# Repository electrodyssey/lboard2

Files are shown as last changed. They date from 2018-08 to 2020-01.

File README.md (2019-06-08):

experimental sound processing board with XC6SLX9-TQG144 and TLV320AIC3204

Work is in progress. 

Currently board is capable of receiving and sending the audio samples with a codec and passes the loopback test from FPGA pins.

FPGA bitstream config is stored inside the STM32F401RE internal flash.

Quick and dirty firmware loader is here: https://github.com/electrodyssey/lboard2flashboot

Working full-duplex aic3204 configuration script is saved in aic3204script directory:

codec receives: MCLK = 11.2896 MHz,

and generates: BLCK = 2.8224 MHz,

WCLK = 44.1 kHz

Please check the CHANGELOG  for the updates

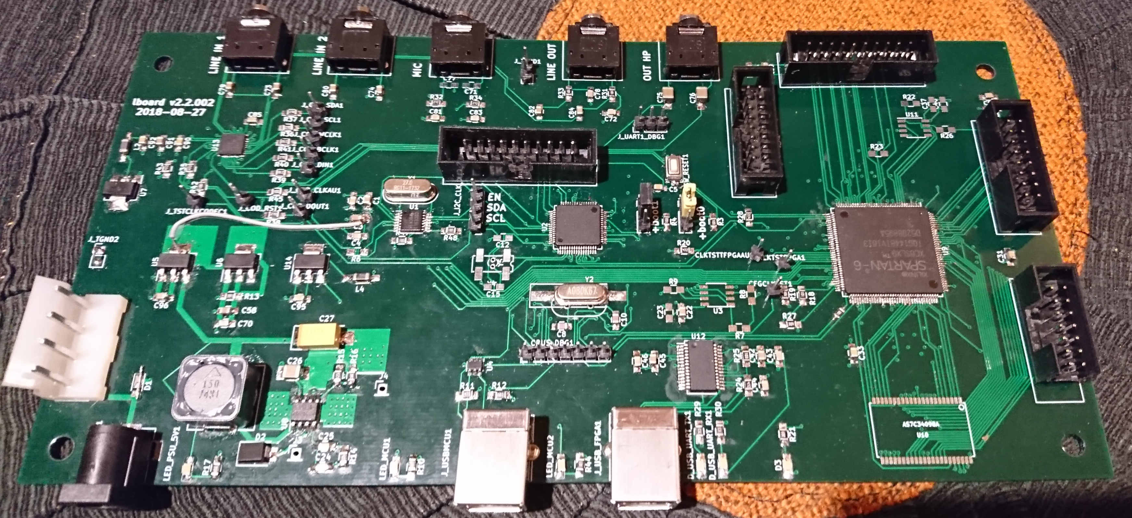
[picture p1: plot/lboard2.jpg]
lboard2


Block diagram:

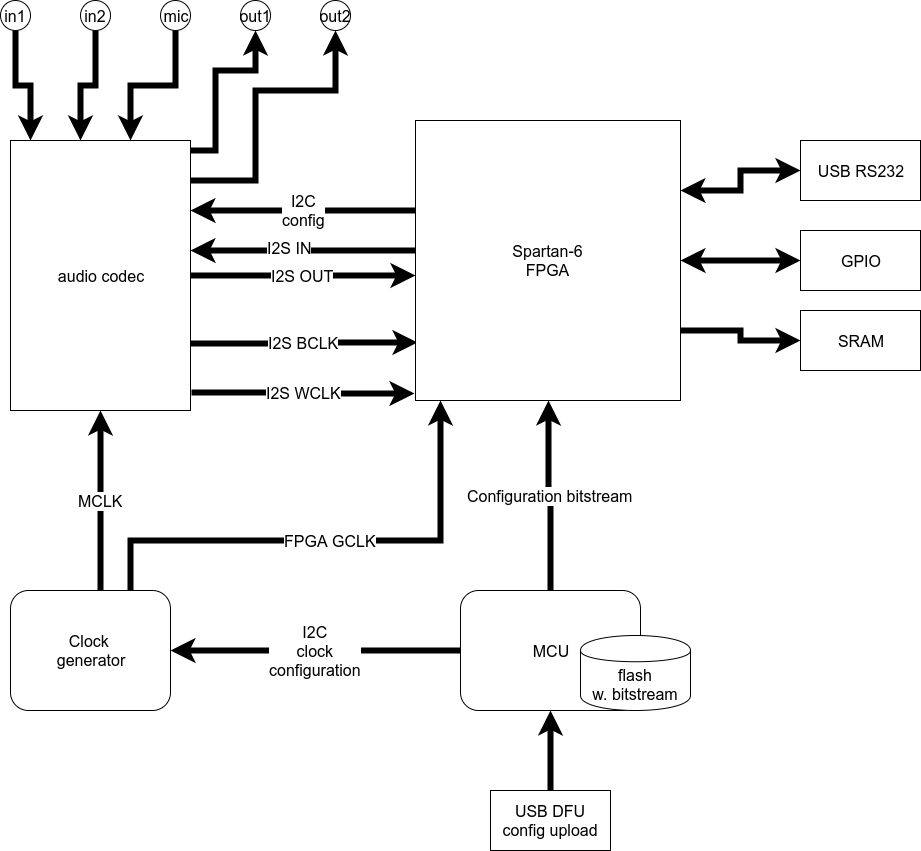
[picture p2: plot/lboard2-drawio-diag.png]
lboard2 block diagram


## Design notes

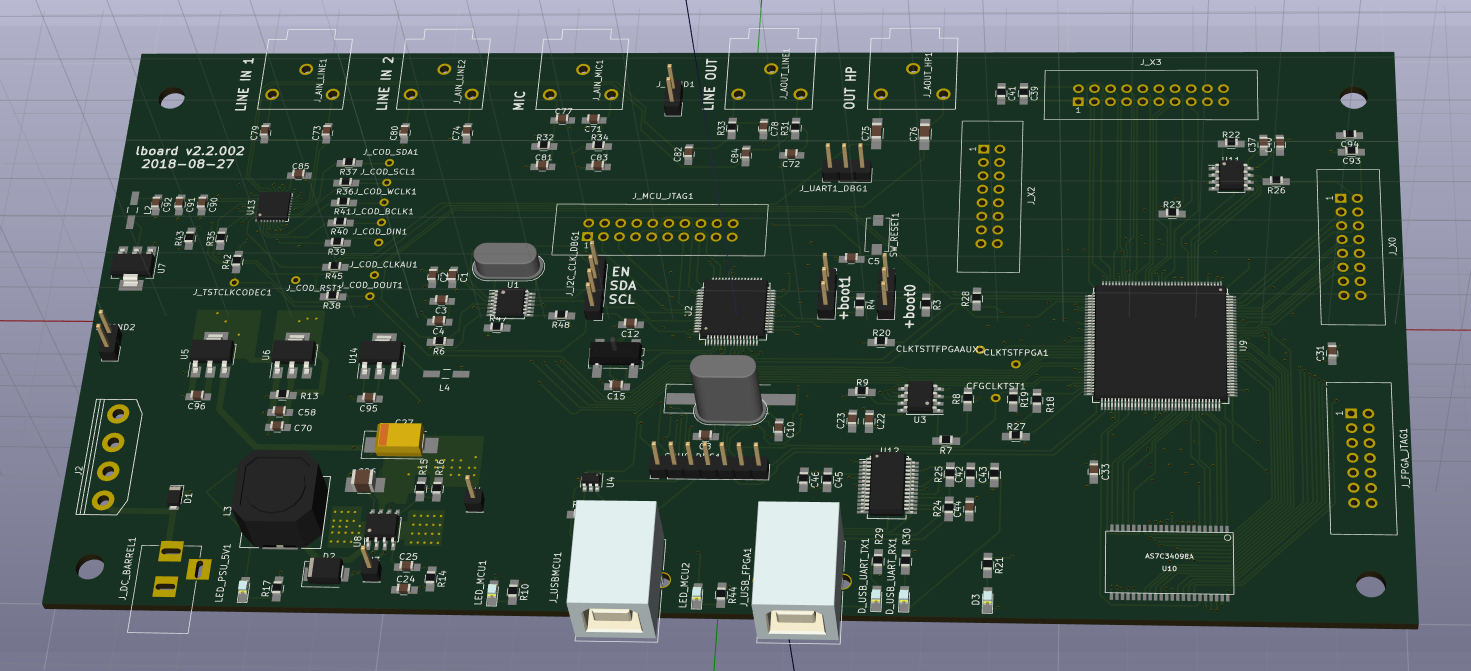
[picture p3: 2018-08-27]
plot/board.png

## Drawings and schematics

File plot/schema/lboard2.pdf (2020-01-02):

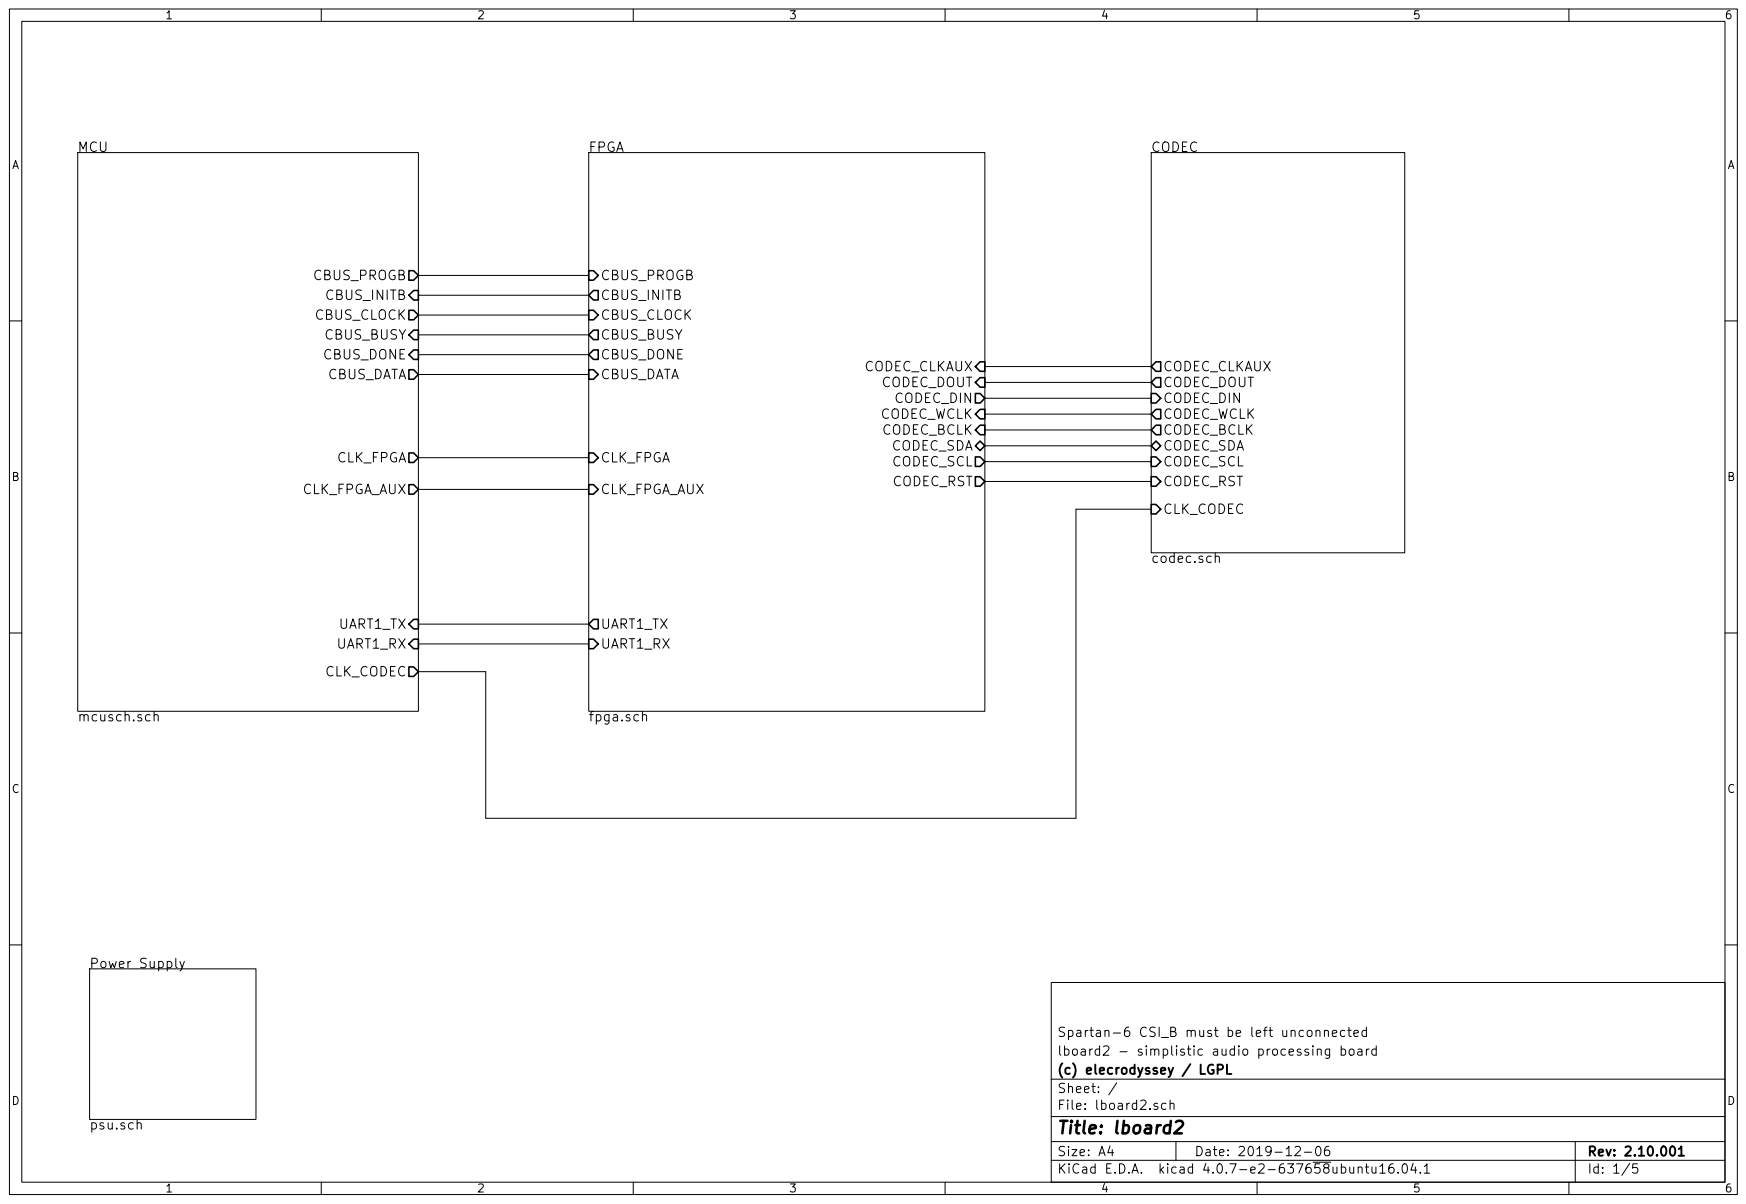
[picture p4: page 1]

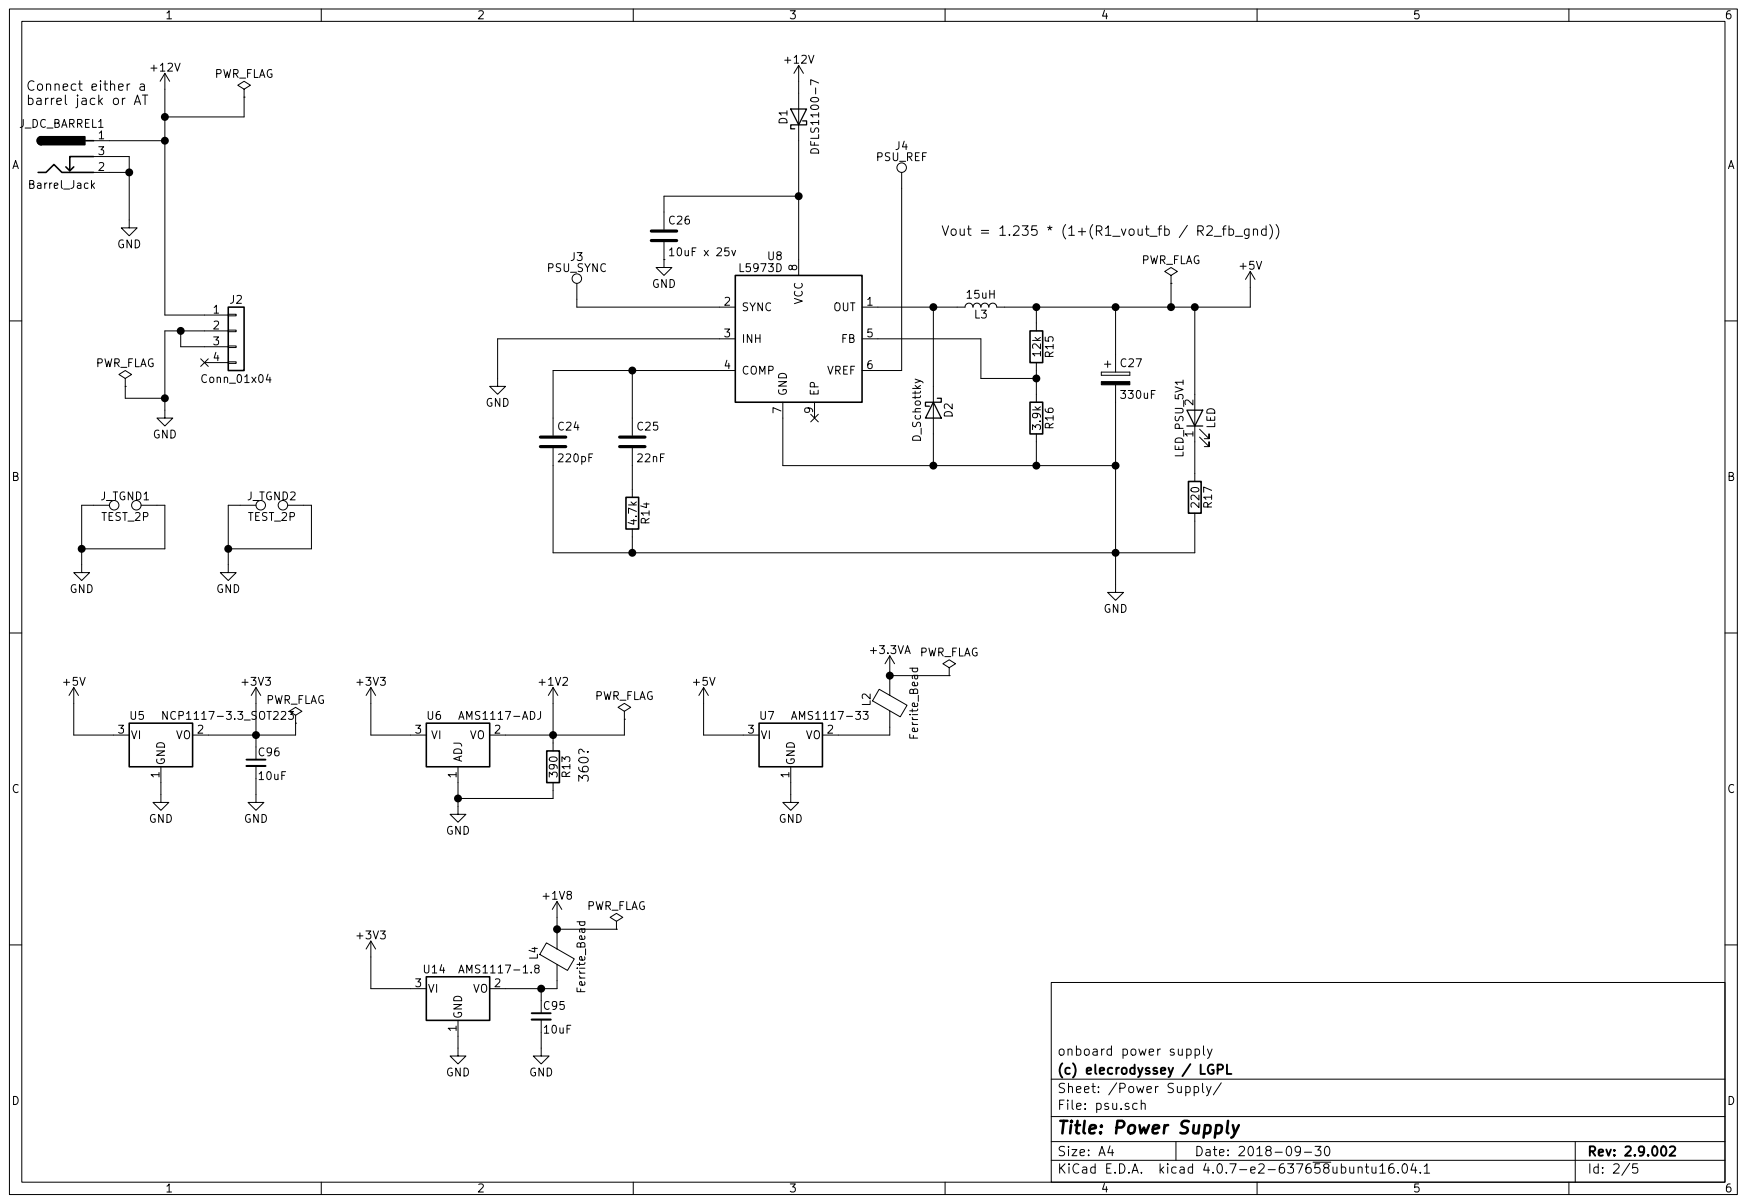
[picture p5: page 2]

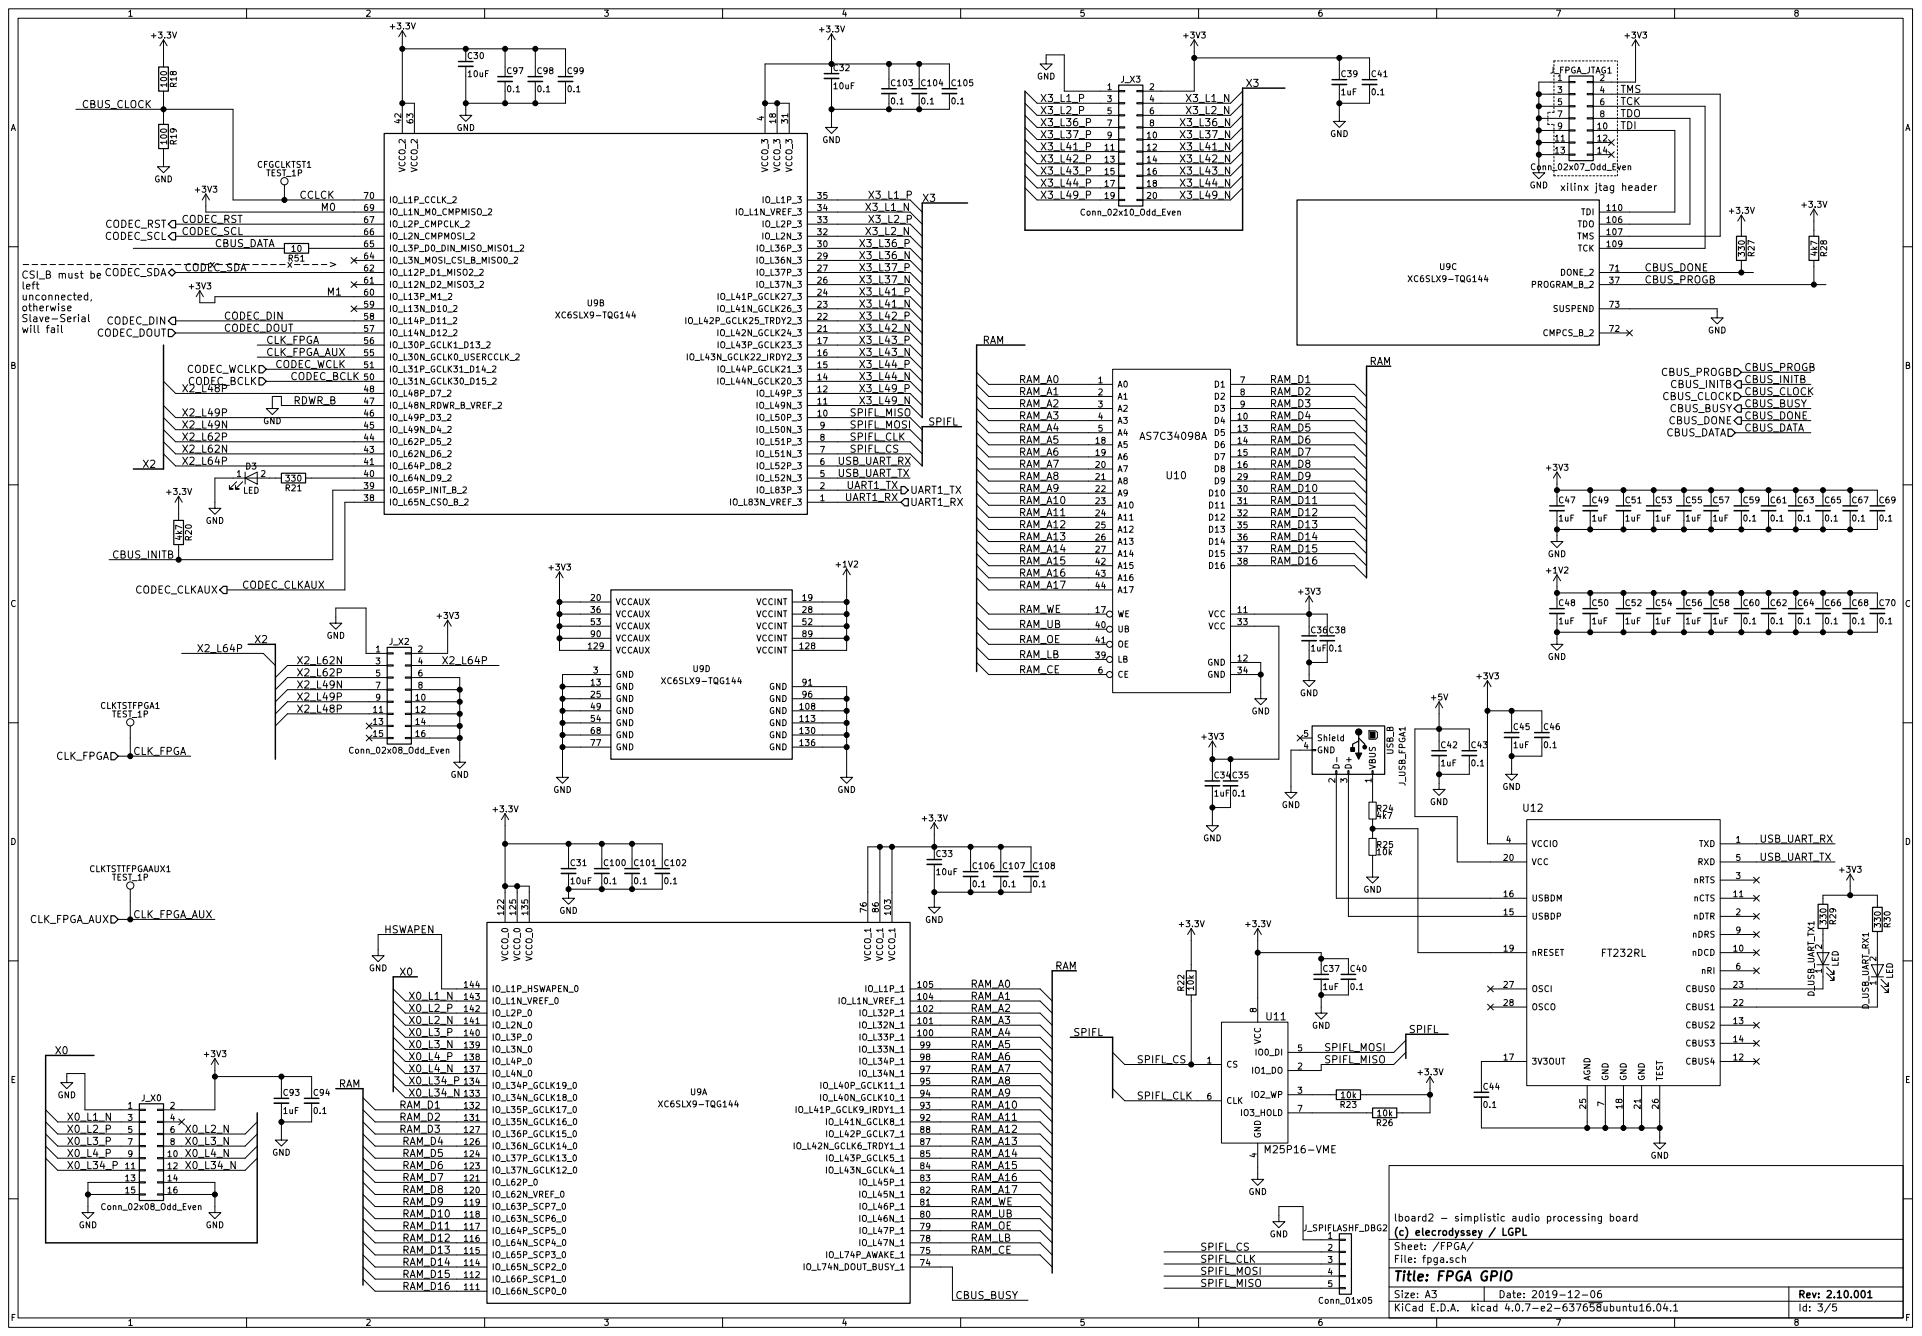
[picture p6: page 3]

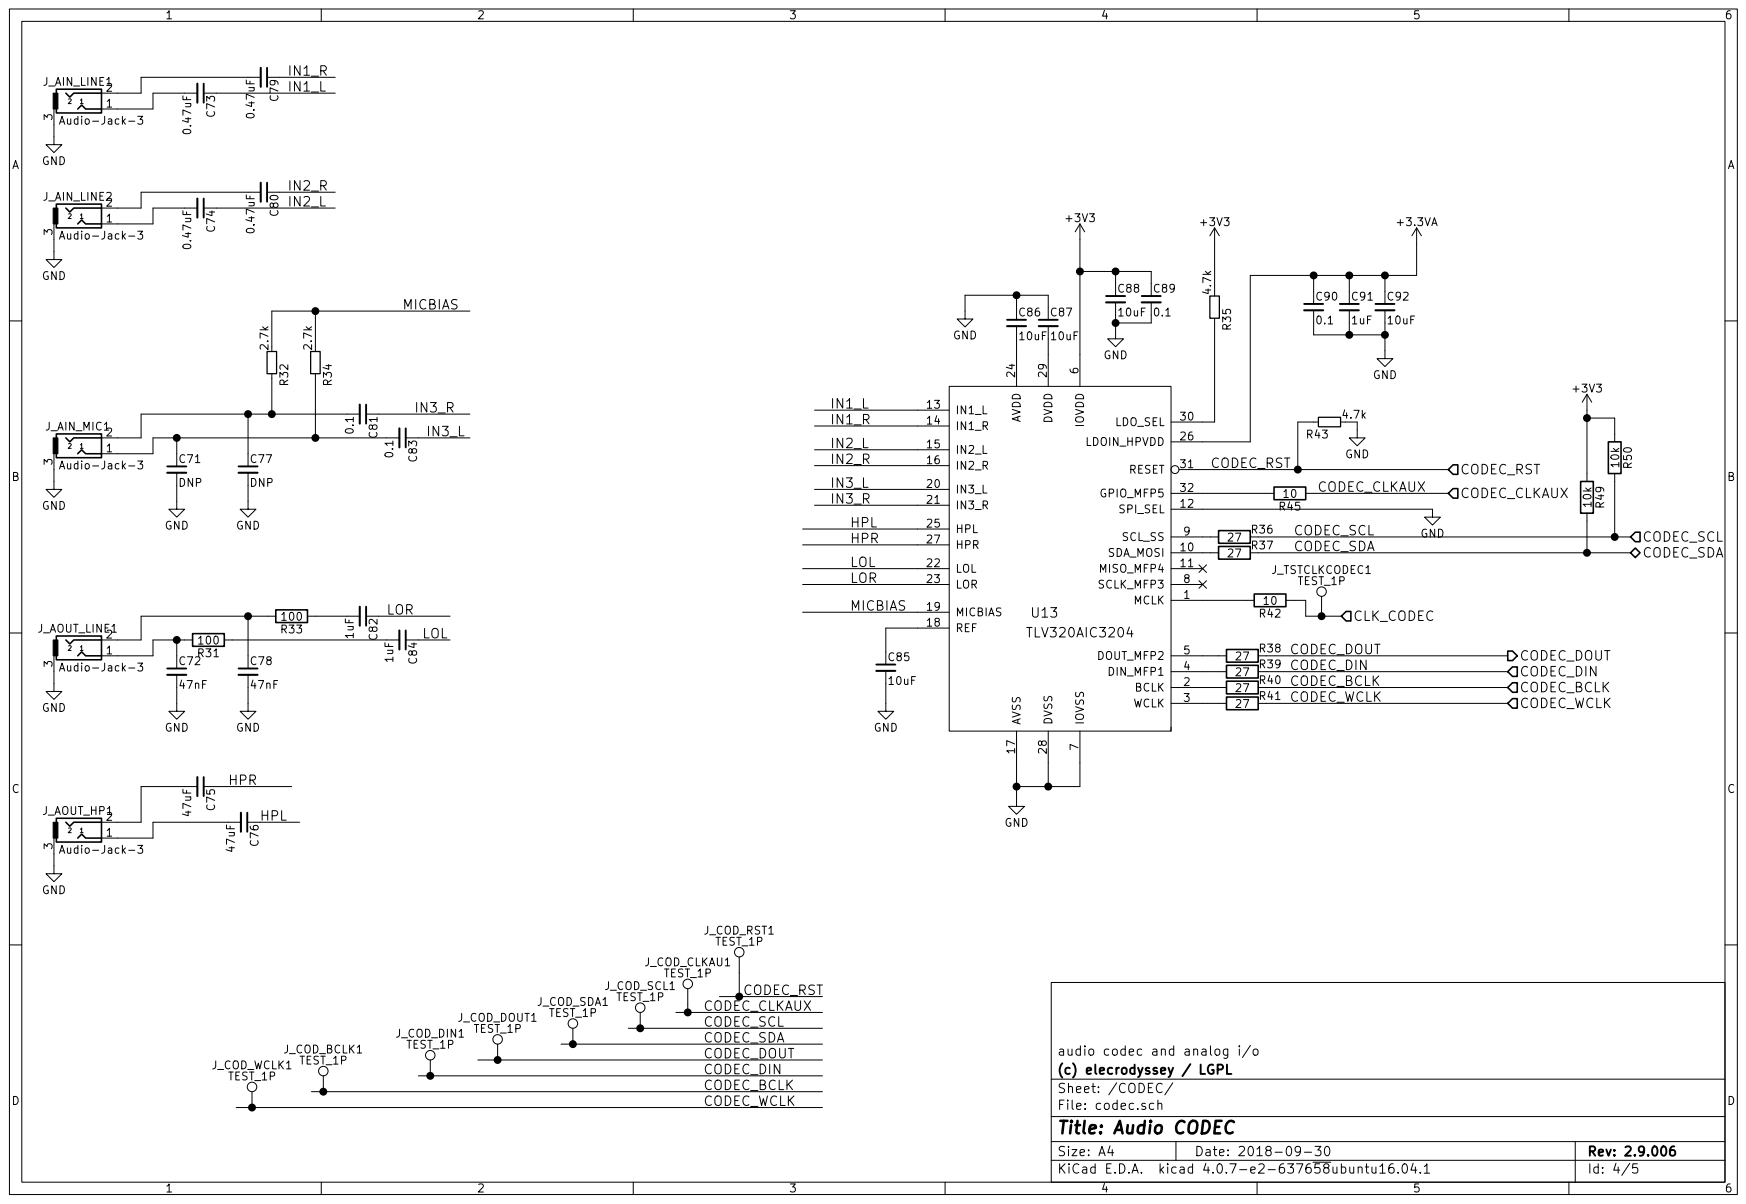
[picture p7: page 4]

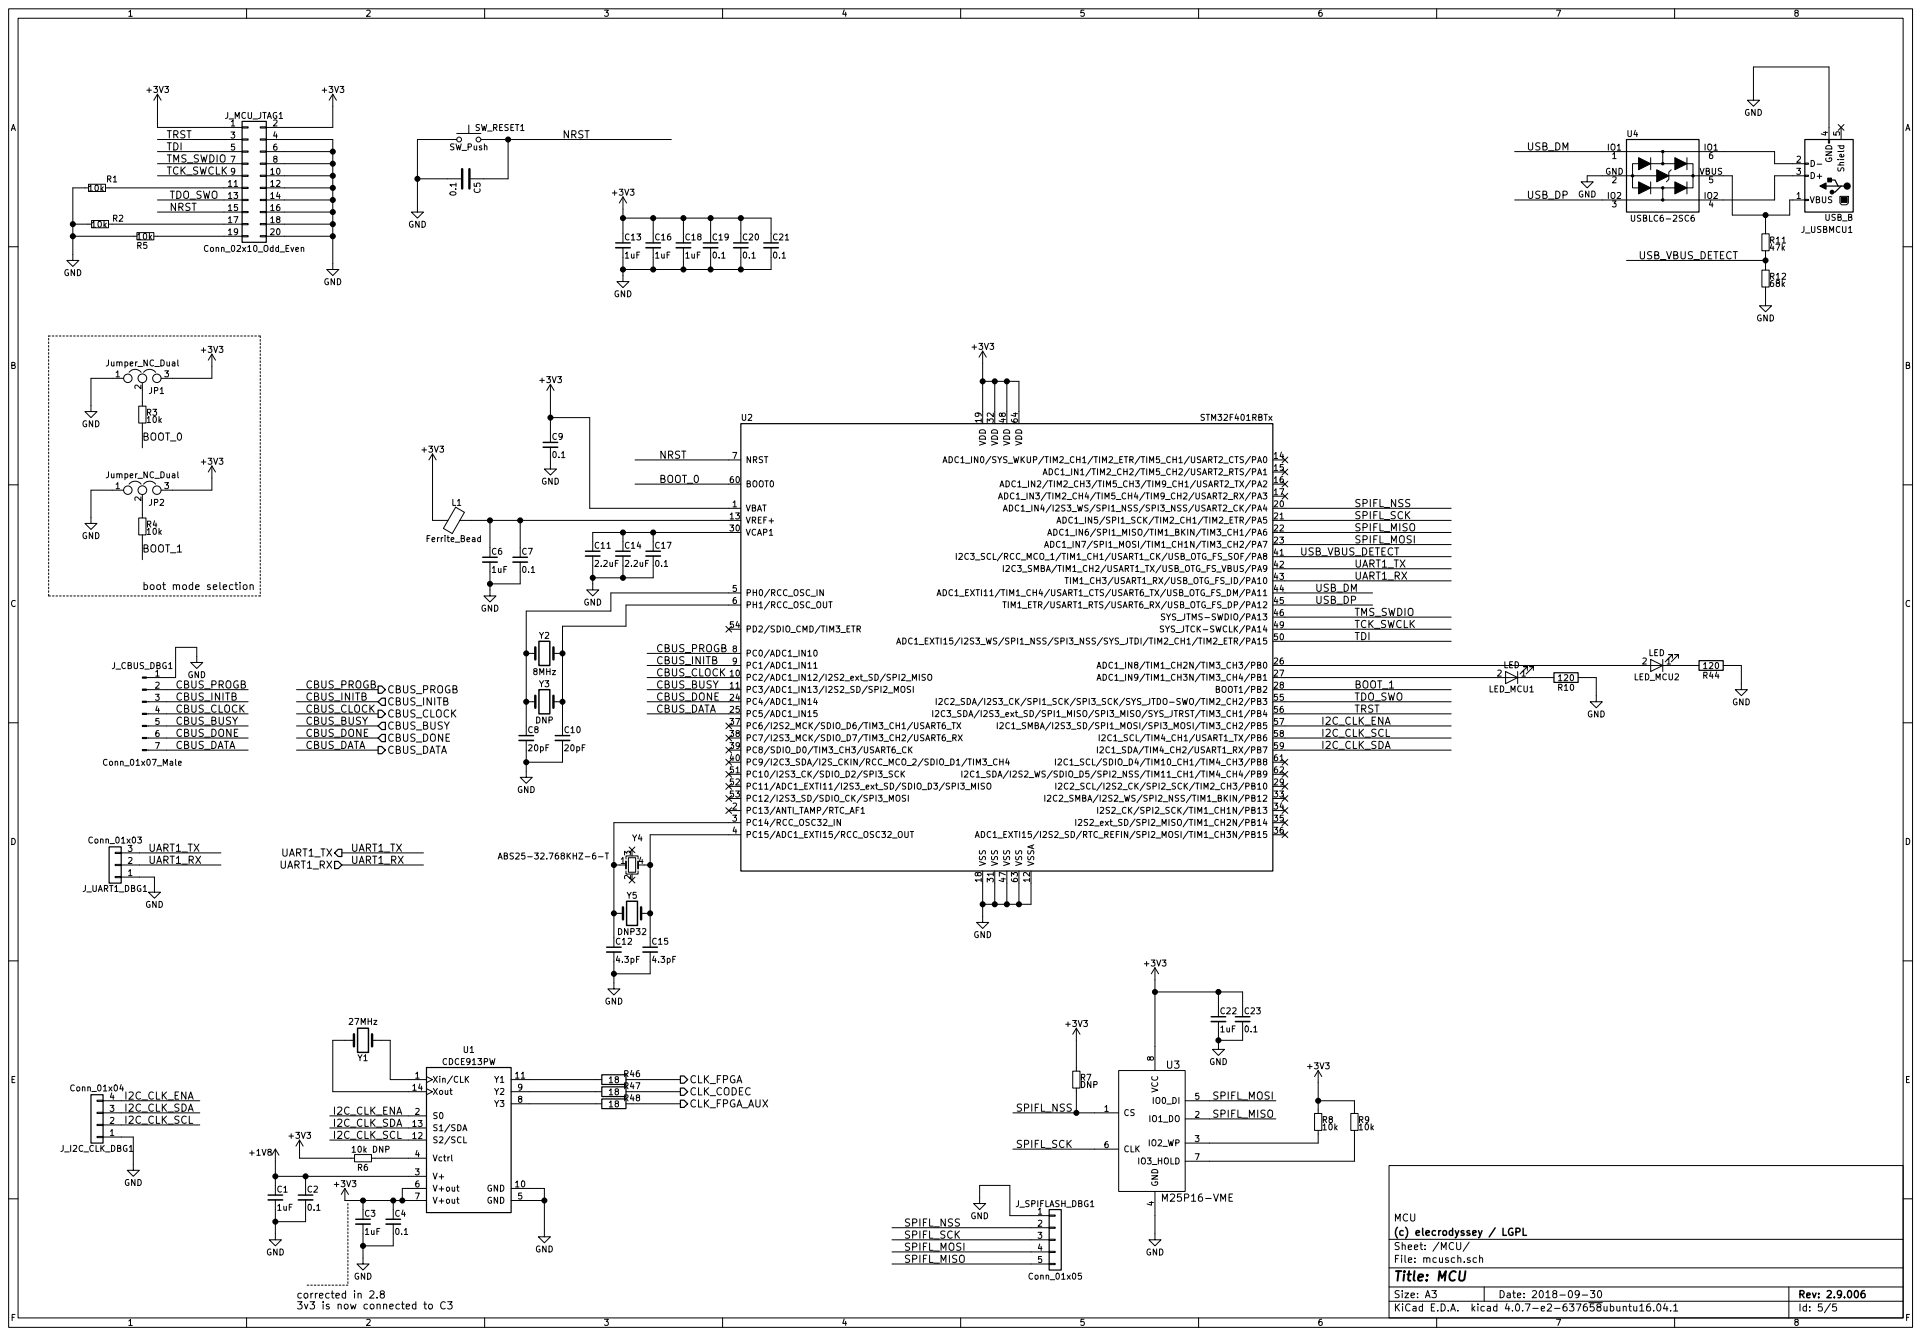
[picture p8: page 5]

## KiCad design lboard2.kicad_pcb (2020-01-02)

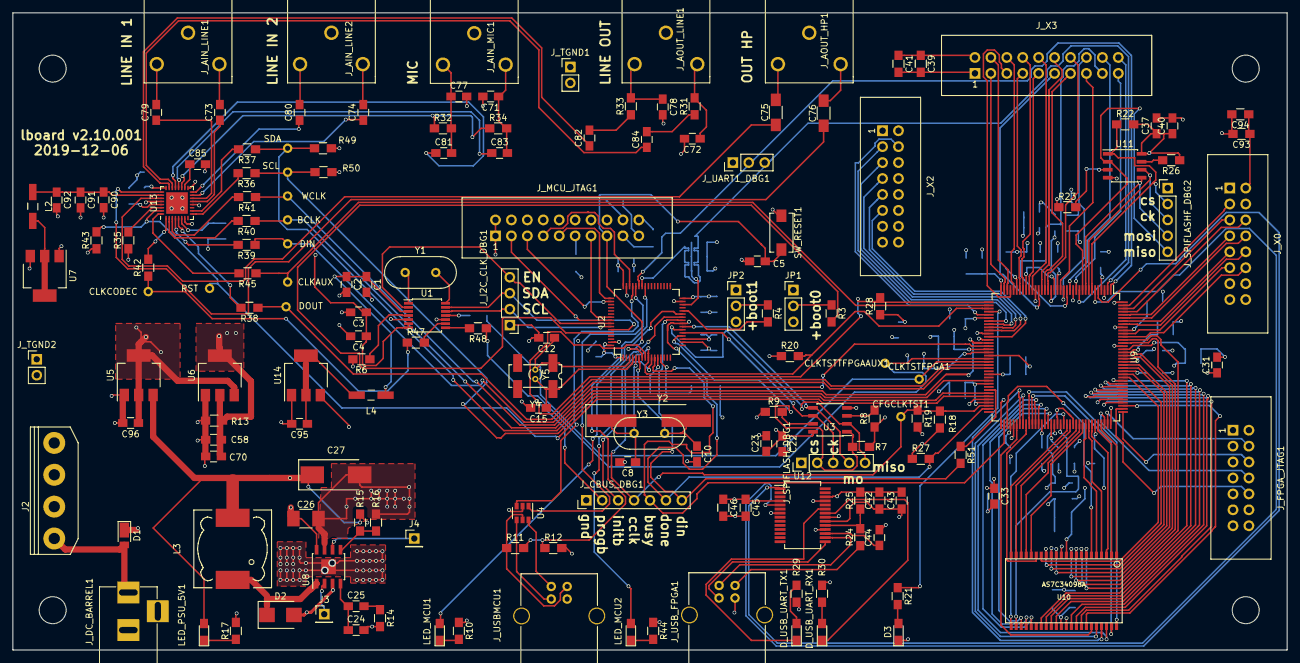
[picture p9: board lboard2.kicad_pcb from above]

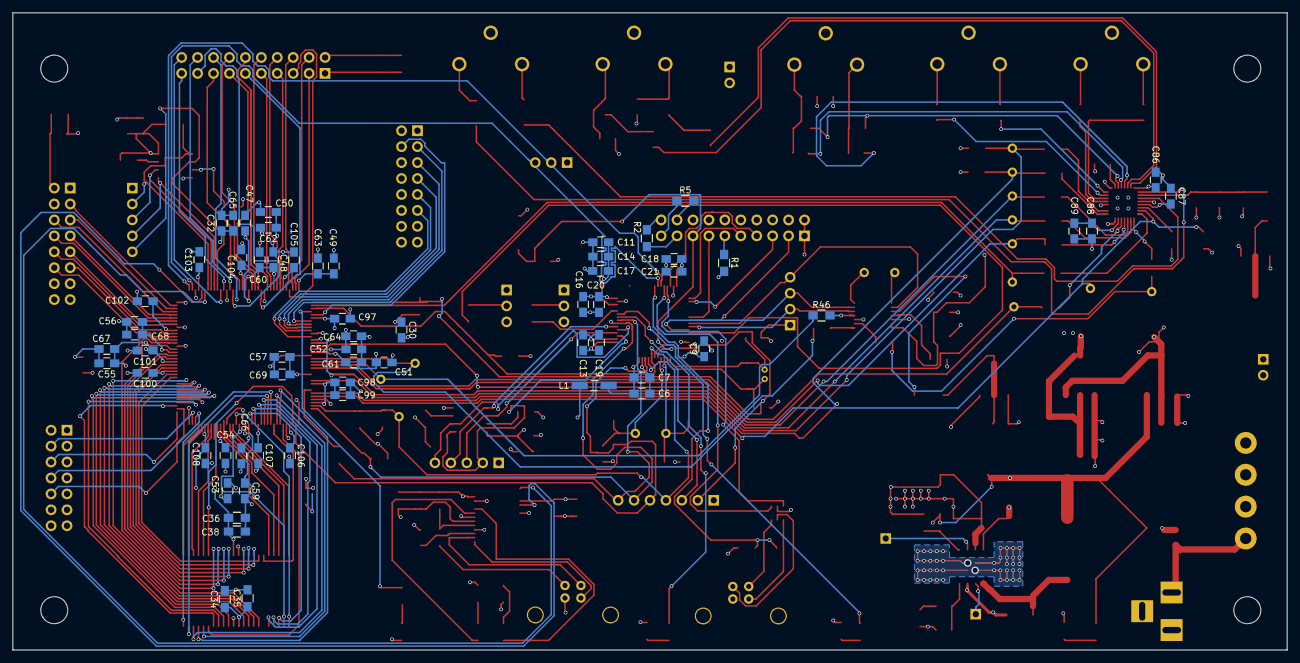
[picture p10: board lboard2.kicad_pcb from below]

Board: 4 copper layers, 203.2 x 101.6 mm, 230 parts (61 on the bottom side), 211 nets.

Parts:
BCLK: TEST_1P; Measurement_Point_Round-TH_Small
C1, C3, C6, C13, C16, C18, C22, C37, C47, C48, C49, C50, C51, C52, C53, C54, C55, C56, C57, C58, C82, C84, C91: 1uF; C_0805_HandSoldering
C2, C4, C5, C7, C9, C17, C19, C20, C21, C23, C40, C44, C59, C60, C61, C62, C63, C64, C65, C66, C67, C68, C69, C70, C81, C83, C89, C90, C97, C98, C99, C100, C101, C102, C103, C104, C105, C106, C107, C108: 0.1; C_0805_HandSoldering
C8, C10: 20pF; C_0805_HandSoldering
C11, C14: 2.2uF; C_0805_HandSoldering
C12, C15: 4.3pF; C_0805_HandSoldering
C24: 220pF; C_0805_HandSoldering
C25: 22nF; C_0805_HandSoldering
C26: 10uF x 25v; C_1210_HandSoldering
C27: 330uF; CP_Tantalum_Case-D_EIA-7343-31_Hand
C30, C31, C32, C33, C85, C86, C87, C88, C92, C95, C96: 10uF; C_0805_HandSoldering
C34, C36, C39, C42, C45, C93: 1uF; R_0805_HandSoldering
C35, C38, C41, C43, C46, C94: 0.1; R_0805_HandSoldering
C71, C77: DNP; C_0805_HandSoldering
C72, C78: 47nF; C_0805_HandSoldering
C73, C74, C79, C80: 0.47uF; C_0805_HandSoldering
C75, C76: 47uF; C_1206_HandSoldering
CFGCLKTST1: TEST_1P; Measurement_Point_Round-TH_Small
CLKAUX: TEST_1P; Measurement_Point_Round-TH_Small
CLKCODEC: TEST_1P; Measurement_Point_Round-TH_Small
CLKTSTFPGA1: TEST_1P; Measurement_Point_Round-TH_Small
CLKTSTTFPGAAUX1: TEST_1P; Measurement_Point_Round-TH_Small
D1: DFLS1100-7; D_PowerDI-123
D2: D_Schottky; D_SMB
D3: LED; LED_0805_HandSoldering
DIN: TEST_1P; Measurement_Point_Round-TH_Small
DOUT: TEST_1P; Measurement_Point_Round-TH_Small
D_USB_UART_RX1: LED; LED_0805_HandSoldering
D_USB_UART_TX1: LED; LED_0805_HandSoldering
J2: Conn_01x04; ATX-PSU-MOLEX-4PIN-5.08mm
J3: PSU_SYNC; Pin_Header_Straight_1x01_Pitch2.54mm
J4: PSU_REF; Pin_Header_Straight_1x01_Pitch2.54mm
JP1, JP2: Jumper_NC_Dual; Pin_Header_Straight_1x03_Pitch2.54mm
J_AIN_LINE1, J_AIN_LINE2: Audio-Jack-3; audiosock-3.5-3pin
J_AIN_MIC1: Audio-Jack-3; audiosock-3.5-3pin
J_AOUT_HP1: Audio-Jack-3; audiosock-3.5-3pin
J_AOUT_LINE1: Audio-Jack-3; audiosock-3.5-3pin
J_CBUS_DBG1: Conn_01x07_Male; Pin_Header_Straight_1x07_Pitch2.54mm
J_DC_BARREL1: Barrel_Jack; BARREL_JACK
J_FPGA_JTAG1: Conn_02x07_Odd_Even; IDC_Header_Straight_14pins
J_I2C_CLK_DBG1: Conn_01x04; Pin_Header_Straight_1x04_Pitch2.54mm
J_MCU_JTAG1: Conn_02x10_Odd_Even; IDC_Header_Straight_20pins
J_SPIFLASHF_DBG2: Conn_01x05; Pin_Header_Straight_1x05_Pitch2.54mm
J_SPIFLASH_DBG1: Conn_01x05; Pin_Header_Straight_1x05_Pitch2.54mm
J_TGND1, J_TGND2: TEST_2P; Pin_Header_Straight_1x02_Pitch2.54mm
J_UART1_DBG1: Conn_01x03; Pin_Header_Straight_1x03_Pitch2.54mm
J_USBMCU1: USB_B
J_USB_FPGA1: USB_B
J_X0, J_X2: Conn_02x08_Odd_Even; IDC_Header_Straight_16pins
J_X3: Conn_02x10_Odd_Even; IDC_Header_Straight_20pins
L1, L2, L4: Ferrite_Bead; Choke_SMD_1206_Handsoldering
L3: 15uH; Choke_SMD_12x12mm_h8mm
LED_MCU1, LED_MCU2: LED; LED_0805_HandSoldering
LED_PSU_5V1: LED; LED_0805_HandSoldering
MH0, MH1, MH2, MH3: MountingHole_4.3mm_M4_DIN965
R1, R2, R3, R4, R5, R8, R9, R22, R23, R25, R26, R49, R50: 10k; R_0805_HandSoldering
R6: 10k DNP; R_0805_HandSoldering
R7: DNP; R_0805_HandSoldering
R10, R44: 120; R_0805_HandSoldering
R11: 47k; R_0805_HandSoldering
R12: 68k; R_0805_HandSoldering
R13: 390; R_0805_HandSoldering
R14, R35, R43: 4.7k; R_0805_HandSoldering
R15: 12k; R_0805_HandSoldering
R16: 3.9k; R_0805_HandSoldering
R17: 220; R_0805_HandSoldering
R18, R19, R31, R33: 100; R_0805_HandSoldering
R20, R24, R28: 4k7; R_0805_HandSoldering
R21, R27, R29, R30: 330; R_0805_HandSoldering
R32, R34: 2.7k; R_0805_HandSoldering
R36, R37, R38, R39, R40, R41: 27; R_0805_HandSoldering
R42, R45, R51: 10; R_0805_HandSoldering
R46, R47, R48: 18; R_0805_HandSoldering
RST: TEST_1P; Measurement_Point_Round-TH_Small
SCL: TEST_1P; Measurement_Point_Round-TH_Small
SDA: TEST_1P; Measurement_Point_Round-TH_Small
SW_RESET1: SW_Push; SW_SPST_EVQPE1
U1: CDCE913PW; TSSOP-14_4.4x5mm_Pitch0.65mm
U2: STM32F401RBTx; LQFP-64_10x10mm_Pitch0.5mm
U3, U11: M25P16-VME; SOIC-8_3.9x4.9mm_Pitch1.27mm
U4: USBLC6-2SC6; SOT-23-6
U5: NCP1117-3.3_SOT223; SOT-223-3_TabPin2
U6: AMS1117-ADJ; SOT-223-3_TabPin2
U7: AMS1117-33; SOT-223-3_TabPin2
U8: L5973D; SOIC-8-1EP_3.9x4.9mm_Pitch1.27mm
U9: XC6SLX9-TQG144; LQFP-144_20x20mm_Pitch0.5mm
U10: AS7C34098A; tsop2-44
U12: FT232RL; SSOP-28_5.3x10.2mm_Pitch0.65mm
U13: TLV320AIC3204; QFN-32-1EP_5x5mm_Pitch0.5mm
U14: AMS1117-1.8; SOT-223-3_TabPin2
WCLK: TEST_1P; Measurement_Point_Round-TH_Small
Y1: 27MHz; Crystal_HC49-4H_Vertical
Y2: 8MHz; Crystal_SMD_HC49-SD_HandSoldering
Y3: DNP; Crystal_HC49-U_Vertical
Y4: ABS25-32.768KHZ-6-T; Crystal_SMD_SeikoEpson_MC306-4pin_8.0x3.2mm_HandSoldering
Y5: DNP32; Crystal_DS10_d1.0mm_l4.3mm_Vertical

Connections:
+1V2: C48.1, C50.1, C52.1, C54.1, C56.1, C58.1, C60.1, C62.1, C64.1, C66.1, C68.1, C70.1, R13.1, U6.2, U9.19, U9.28, U9.52, U9.89, U9.128
+1V8: C1.1, C2.1, L4.1, U1.3
+3.3VA: C90.1, C91.1, C92.1, L2.1, U13.26
+3V3: C3.1, C4.1, C9.1, C13.1, C16.1, C18.1, C19.1, C20.1, C21.1, C22.1, C23.1, C30.1, C31.1, C32.1, C33.1, C34.1, C35.1, C36.1, C37.1, C38.1, C39.1, C40.1, C41.1, C45.1, C46.1, C47.1, C49.1, C51.1, C53.1, C55.1, C57.1, C59.1, C61.1, C63.1, C65.1, C67.1, C69.1, C88.1, C89.1, C93.1, C94.1, C96.1, C97.1, C98.1, C99.1, C100.1, C101.1, C102.1, C103.1, C104.1, C105.1, C106.1, C107.1, C108.1, JP1.3, JP2.3, J_FPGA_JTAG1.2, J_MCU_JTAG1.1, J_MCU_JTAG1.2, J_X0.2, J_X2.2, J_X3.2, L1.2, R6.2, R7.1, R8.1, R9.1, R18.1, R20.1, R22.2, R23.1, R26.1, R27.1, R28.1, R29.1, R30.1, R35.1, R49.1, R50.1, U1.6, U1.7, U2.1, U2.19, U2.32, U2.48, U2.64, U3.8, U5.2, U6.3, U9.4, U9.18, U9.20, U9.31, U9.36, U9.42, U9.53, U9.60, U9.63, U9.69, U9.76, U9.86, U9.90, U9.103, U9.122, U9.125, U9.129, U9.135, U10.11, U10.33, U11.8, U12.4, U13.6, U14.3
+5V: C27.1, C42.1, C43.1, L3.2, LED_PSU_5V1.2, R15.1, U5.3, U7.3, U12.20
+12V: D1.2, J2.1, J_DC_BARREL1.1
/CODEC/CLK_CODEC: CLKCODEC.1, R42.1, R47.1
/CODEC/CODEC_BCLK: BCLK.1, R40.1, U9.50
/CODEC/CODEC_CLKAUX: CLKAUX.1, R45.1, U9.38
/CODEC/CODEC_DIN: DIN.1, R39.1, U9.58
/CODEC/CODEC_DOUT: DOUT.1, R38.1, U9.57
/CODEC/CODEC_RST: R43.2, RST.1, U9.67, U13.31
/CODEC/CODEC_SCL: R36.1, R50.2, SCL.1, U9.66
/CODEC/CODEC_SDA: R37.1, R49.2, SDA.1, U9.62
/CODEC/CODEC_WCLK: R41.1, U9.51, WCLK.1
/CODEC/HPL: C76.1, U13.25
/CODEC/HPR: C75.1, U13.27
/CODEC/IN1_L: C73.1, U13.13
/CODEC/IN1_R: C79.1, U13.14
/CODEC/IN2_L: C74.1, U13.15
/CODEC/IN2_R: C80.1, U13.16
/CODEC/IN3_L: C83.1, U13.20
/CODEC/IN3_R: C81.1, U13.21
/CODEC/LOL: C84.1, U13.22
/CODEC/LOR: C82.1, U13.23
/CODEC/MICBIAS: R32.1, R34.1, U13.19
/FPGA/CBUS_BUSY: J_CBUS_DBG1.5, U2.11, U9.74
/FPGA/CBUS_CLOCK: CFGCLKTST1.1, J_CBUS_DBG1.4, R18.2, R19.1, U2.10, U9.70
/FPGA/CBUS_DATA: J_CBUS_DBG1.7, R51.2, U2.25
/FPGA/CBUS_DONE: J_CBUS_DBG1.6, R27.2, U2.24, U9.71
/FPGA/CBUS_INITB: J_CBUS_DBG1.3, R20.2, U2.9, U9.39
/FPGA/CBUS_PROGB: J_CBUS_DBG1.2, R28.2, U2.8, U9.37
/FPGA/CLK_FPGA: CLKTSTFPGA1.1, R46.1, U9.56
/FPGA/CLK_FPGA_AUX: CLKTSTTFPGAAUX1.1, R48.1, U9.55
/FPGA/RAM_A0: U9.105, U10.1
/FPGA/RAM_A1: U9.104, U10.2
/FPGA/RAM_A2: U9.102, U10.3
/FPGA/RAM_A3: U9.101, U10.4
/FPGA/RAM_A4: U9.100, U10.5
/FPGA/RAM_A5: U9.99, U10.18
/FPGA/RAM_A6: U9.98, U10.19
/FPGA/RAM_A7: U9.97, U10.20
/FPGA/RAM_A8: U9.95, U10.21
/FPGA/RAM_A9: U9.94, U10.22
/FPGA/RAM_A10: U9.93, U10.23
/FPGA/RAM_A11: U9.92, U10.24
/FPGA/RAM_A12: U9.88, U10.25
/FPGA/RAM_A13: U9.87, U10.26
/FPGA/RAM_A14: U9.85, U10.27
/FPGA/RAM_A15: U9.84, U10.42
/FPGA/RAM_A16: U9.83, U10.43
/FPGA/RAM_A17: U9.82, U10.44
/FPGA/RAM_CE: U9.75, U10.6
/FPGA/RAM_D1: U9.132, U10.7
/FPGA/RAM_D2: U9.131, U10.8
/FPGA/RAM_D3: U9.127, U10.9
/FPGA/RAM_D4: U9.126, U10.10
/FPGA/RAM_D5: U9.124, U10.13
/FPGA/RAM_D6: U9.123, U10.14
/FPGA/RAM_D7: U9.121, U10.15
/FPGA/RAM_D8: U9.120, U10.16
/FPGA/RAM_D9: U9.119, U10.29
/FPGA/RAM_D10: U9.118, U10.30
/FPGA/RAM_D11: U9.117, U10.31
/FPGA/RAM_D12: U9.116, U10.32
/FPGA/RAM_D13: U9.115, U10.35
/FPGA/RAM_D14: U9.114, U10.36
/FPGA/RAM_D15: U9.112, U10.37
/FPGA/RAM_D16: U9.111, U10.38
/FPGA/RAM_LB: U9.78, U10.39
/FPGA/RAM_OE: U9.79, U10.41
/FPGA/RAM_UB: U9.80, U10.40
/FPGA/RAM_WE: U9.81, U10.17
/FPGA/SPIFL_CLK: J_SPIFLASHF_DBG2.3, U9.8, U11.6
/FPGA/SPIFL_CS: J_SPIFLASHF_DBG2.2, R22.1, U9.7, U11.1
/FPGA/SPIFL_MISO: J_SPIFLASHF_DBG2.5, U9.10, U11.2
/FPGA/SPIFL_MOSI: J_SPIFLASHF_DBG2.4, U9.9, U11.5
/FPGA/TCK: J_FPGA_JTAG1.6, U9.109
/FPGA/TDI: J_FPGA_JTAG1.10, U9.110
/FPGA/TDO: J_FPGA_JTAG1.8, U9.106
/FPGA/TMS: J_FPGA_JTAG1.4, U9.107
/FPGA/UART1_RX: J_UART1_DBG1.2, U2.43, U9.1
/FPGA/UART1_TX: J_UART1_DBG1.3, U2.42, U9.2
/FPGA/USB_UART_RX: U9.6, U12.1
/FPGA/USB_UART_TX: U9.5, U12.5
/FPGA/X0_L1_N: J_X0.3, U9.143
/FPGA/X0_L2_N: J_X0.6, U9.141
/FPGA/X0_L2_P: J_X0.5, U9.142
/FPGA/X0_L3_N: J_X0.8, U9.139
/FPGA/X0_L3_P: J_X0.7, U9.140
/FPGA/X0_L4_N: J_X0.10, U9.137
/FPGA/X0_L4_P: J_X0.9, U9.138
/FPGA/X0_L34_N: J_X0.12, U9.133
/FPGA/X0_L34_P: J_X0.11, U9.134
/FPGA/X2_L48P: J_X2.11, U9.48
/FPGA/X2_L49N: J_X2.7, U9.45
/FPGA/X2_L49P: J_X2.9, U9.46
/FPGA/X2_L62N: J_X2.3, U9.43
/FPGA/X2_L62P: J_X2.5, U9.44
/FPGA/X2_L64P: J_X2.4, U9.41
/FPGA/X3_L1_N: J_X3.4, U9.34
/FPGA/X3_L1_P: J_X3.3, U9.35
/FPGA/X3_L2_N: J_X3.6, U9.32
/FPGA/X3_L2_P: J_X3.5, U9.33
/FPGA/X3_L36_N: J_X3.8, U9.29
/FPGA/X3_L36_P: J_X3.7, U9.30
/FPGA/X3_L37_N: J_X3.10, U9.26
/FPGA/X3_L37_P: J_X3.9, U9.27
/FPGA/X3_L41_N: J_X3.12, U9.23
/FPGA/X3_L41_P: J_X3.11, U9.24
/FPGA/X3_L42_N: J_X3.14, U9.21
/FPGA/X3_L42_P: J_X3.13, U9.22
/FPGA/X3_L43_N: J_X3.16, U9.16
/FPGA/X3_L43_P: J_X3.15, U9.17
/FPGA/X3_L44_N: J_X3.18, U9.14
/FPGA/X3_L44_P: J_X3.17, U9.15
/FPGA/X3_L49_N: J_X3.20, U9.11
/FPGA/X3_L49_P: J_X3.19, U9.12
/MCU/BOOT_0: R3.2, U2.60
/MCU/BOOT_1: R4.2, U2.28
/MCU/I2C_CLK_ENA: J_I2C_CLK_DBG1.4, U1.2, U2.57
/MCU/I2C_CLK_SCL: J_I2C_CLK_DBG1.2, U1.12, U2.58
/MCU/I2C_CLK_SDA: J_I2C_CLK_DBG1.3, U1.13, U2.59
/MCU/NRST: C5.1, J_MCU_JTAG1.15, SW_RESET1.2, U2.7
/MCU/SPIFL_MISO: J_SPIFLASH_DBG1.5, U2.22, U3.2
/MCU/SPIFL_MOSI: J_SPIFLASH_DBG1.4, U2.23, U3.5
/MCU/SPIFL_NSS: J_SPIFLASH_DBG1.2, R7.2, U2.20, U3.1
/MCU/SPIFL_SCK: J_SPIFLASH_DBG1.3, U2.21, U3.6
/MCU/TCK_SWCLK: J_MCU_JTAG1.9, U2.49
/MCU/TDI: J_MCU_JTAG1.5, U2.50
/MCU/TDO_SWO: J_MCU_JTAG1.13, U2.55
/MCU/TMS_SWDIO: J_MCU_JTAG1.7, U2.46
/MCU/TRST: J_MCU_JTAG1.3, U2.56
/MCU/USB_DM: U2.44, U4.1
/MCU/USB_DP: U2.45, U4.3
/MCU/USB_VBUS_DETECT: R11.2, R12.1, U2.41
GND: C1.2, C2.2, C3.2, C4.2, C5.2, C6.2, C7.2, C8.2, C9.2, C10.2, C11.2, C12.2, C13.2, C14.2, C15.2, C16.2, C17.2, C18.2, C19.2, C20.2, C21.2, C22.2, C23.2, C24.2, C26.2, C27.2, C30.2, C31.2, C32.2, C33.2, C34.2, C35.2, C36.2, C37.2, C38.2, C39.2, C40.2, C41.2, C42.2, C43.2, C44.2, C45.2, C46.2, C47.2, C48.2, C49.2, C50.2, C51.2, C52.2, C53.2, C54.2, C55.2, C56.2, C57.2, C58.2, C59.2, C60.2, C61.2, C62.2, C63.2, C64.2, C65.2, C66.2, C67.2, C68.2, C69.2, C70.2, C71.2, C72.2, C77.2, C78.2, C85.2, C86.1, C87.1, C88.2, C89.2, C90.2, C91.2, C92.2, C93.2, C94.2, C95.2, C96.2, C97.2, C98.2, C99.2, C100.2, C101.2, C102.2, C103.2, C104.2, C105.2, C106.2, C107.2, C108.2, D2.2, D3.1, J2.2, J2.3, JP1.1, JP2.1, J_AIN_LINE1.3, J_AIN_LINE2.3, J_AIN_MIC1.3, J_AOUT_HP1.3, J_AOUT_LINE1.3, J_CBUS_DBG1.1, J_DC_BARREL1.2, J_DC_BARREL1.3, J_FPGA_JTAG1.1, J_FPGA_JTAG1.3, J_FPGA_JTAG1.5, J_FPGA_JTAG1.7, J_FPGA_JTAG1.9, J_FPGA_JTAG1.11, J_FPGA_JTAG1.13, J_I2C_CLK_DBG1.1, J_MCU_JTAG1.4, J_MCU_JTAG1.6, J_MCU_JTAG1.8, J_MCU_JTAG1.10, J_MCU_JTAG1.12, J_MCU_JTAG1.14, J_MCU_JTAG1.16, J_MCU_JTAG1.18, J_MCU_JTAG1.20, J_SPIFLASHF_DBG2.1, J_SPIFLASH_DBG1.1, J_TGND1.1, J_TGND1.2, J_TGND2.1, J_TGND2.2, J_UART1_DBG1.1, J_USBMCU1.4, J_USB_FPGA1.4, J_X0.1, J_X0.13, J_X0.14, J_X0.15, J_X0.16, J_X2.1, J_X2.6, J_X2.8, J_X2.10, J_X2.12, J_X2.14, J_X2.16, J_X3.1, R1.2, R2.2, R5.2, R10.1, R12.2, R13.2, R14.2, R16.2, R17.2, R19.2, R25.2, R43.1, R44.1, SW_RESET1.1, U1.5, U1.10, U2.12, U2.18, U2.31, U2.47, U2.63, U3.4, U4.2, U5.1, U6.1, U7.1, U8.3, U8.7, U9.3, U9.13, U9.25, U9.47, U9.49, U9.54, U9.68, U9.73, U9.77, U9.91, U9.96, U9.108, U9.113, U9.130, U9.136, U9.144, U10.12, U10.34, U11.4, U12.7, U12.18, U12.21, U12.25, U12.26, U13.7, U13.12, U13.17, U13.28, U14.1
unnamed: C6.1, C7.1, L1.1, U2.13
unnamed: C8.1, U2.5, Y2.1, Y3.1
unnamed: C10.1, U2.6, Y2.2, Y3.2
unnamed: C11.1, C14.1, C17.1, U2.30
unnamed: C12.1, U2.3, Y4.1, Y5.1
unnamed: C15.1, U2.4, Y4.4, Y5.2
unnamed: C24.1, C25.1, U8.4
unnamed: C25.2, R14.1
unnamed: C26.1, D1.1, U8.8
unnamed: C44.1, U12.17
unnamed: C71.1, C83.2, J_AIN_MIC1.1, R34.2
unnamed: C72.1, J_AOUT_LINE1.1, R31.2
unnamed: C73.2, J_AIN_LINE1.1
unnamed: C74.2, J_AIN_LINE2.1
unnamed: C75.2, J_AOUT_HP1.2
unnamed: C76.2, J_AOUT_HP1.1
unnamed: C77.1, C81.2, J_AIN_MIC1.2, R32.2
unnamed: C78.1, J_AOUT_LINE1.2, R33.2
unnamed: C79.2, J_AIN_LINE1.2
unnamed: C80.2, J_AIN_LINE2.2
unnamed: C82.2, R33.1
unnamed: C84.2, R31.1
unnamed: C85.1, U13.18
unnamed: C86.2, U13.24
unnamed: C87.2, U13.29
unnamed: C95.1, L4.2, U14.2
unnamed: D2.1, L3.1, U8.1
unnamed: D3.2, R21.2
unnamed: D_USB_UART_RX1.1, U12.22
unnamed: D_USB_UART_RX1.2, R30.2
unnamed: D_USB_UART_TX1.1, U12.23
unnamed: D_USB_UART_TX1.2, R29.2
unnamed: J3.1, U8.2
unnamed: J4.1, U8.6
unnamed: JP1.2, R3.1
unnamed: JP2.2, R4.1
unnamed: J_MCU_JTAG1.11, R1.1
unnamed: J_MCU_JTAG1.17, R2.1
unnamed: J_MCU_JTAG1.19, R5.1
unnamed: J_USBMCU1.1, R11.1, U4.5
unnamed: J_USBMCU1.2, U4.6
unnamed: J_USBMCU1.3, U4.4
unnamed: J_USB_FPGA1.1, R24.1
unnamed: J_USB_FPGA1.2, U12.16
unnamed: J_USB_FPGA1.3, U12.15
unnamed: L2.2, U7.2
unnamed: LED_MCU1.1, R10.2
unnamed: LED_MCU1.2, U2.27
unnamed: LED_MCU2.1, R44.2
unnamed: LED_MCU2.2, U2.26
unnamed: LED_PSU_5V1.1, R17.1
unnamed: R6.1, U1.4
unnamed: R8.2, U3.3
unnamed: R9.2, U3.7
unnamed: R15.2, R16.1, U8.5
unnamed: R21.1, U9.40
unnamed: R23.2, U11.3
unnamed: R24.2, R25.1, U12.19
unnamed: R26.2, U11.7
unnamed: R35.2, U13.30
unnamed: R36.2, U13.9
unnamed: R37.2, U13.10
unnamed: R38.2, U13.5
unnamed: R39.2, U13.4
unnamed: R40.2, U13.2
unnamed: R41.2, U13.3
unnamed: R42.2, U13.1
unnamed: R45.2, U13.32
unnamed: R46.2, U1.11
unnamed: R47.2, U1.9
unnamed: R48.2, U1.8
unnamed: R51.1, U9.65
unnamed: U1.1, Y1.1
unnamed: U1.14, Y1.2

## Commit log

2018-08-27 initial import
    [codec.sch, fpga.sch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]
2018-09-27 fixed 3v3 supply on CDCE913 output pin ver. bump
    [lboard2.kicad_pcb, mcusch.sch]
2018-09-27 schematics pdf and board updates
    [lboard2-B.Cu.gbr, lboard2-B.Mask.gbr, lboard2-B.SilkS.gbr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]
2018-09-30 v2.8.001
    SPI flash NSS pullup resistor R7 is marked as DNP.
    LGPL license 3.0 added.
    [codec.sch, fpga.sch, lboard2.sch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]
2018-10-02 work in progress notice, first pcb edition photo
2019-03-22 CSI_B must be left unconnected! ver. bump
    [fpga.sch, lboard2.kicad_pcb, lboard2.sch]
2019-03-22 silkscreen description on a configuration bus
    [fpga.sch, lboard2.kicad_pcb]
2019-03-23 Schematics updates
    U1 CDCDE913 Vctrl pin resistor is marked as DNP. Schematics pdf, gerbers and the photo were updated.
    [codec.sch, lboard2.kicad_pcb, lboard2.sch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]
2019-03-23 Gerbers updated
    [lboard2-B.Cu.gbr, lboard2-B.Mask.gbr, lboard2-B.SilkS.gbr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]
2019-04-04 lboard2 added pullup resistors on a codec i2c bus
    [codec.sch, fpga.sch, lboard2.kicad_pcb]
2019-04-04 lboard2 plot and gerbers updated for 2.9.005
    board and drawings updated for a codec i2c pullup resistors
    [lboard2-B.Cu.gbr, lboard2-B.Mask.gbr, lboard2-B.SilkS.gbr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]
2019-04-06 lboard2 v2.9.006
    added debug headers for spi flash, addedd R51 - serial termination resistor for a CBUS_DATA line
    [codec.sch, fpga.sch, lboard2.kicad_pcb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]
2019-04-06 lboard2 schematics pdf and gerbers updated
    [lboard2-B.Cu.gbr, lboard2-B.Mask.gbr, lboard2-B.SilkS.gbr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]
2019-06-08 block diagram and aic3204 configuration script are added
    [lboard2.sch]
2020-01-02 codec word select and bit clock lines are now routed to an fpga global clock pins
    [fpga.sch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]

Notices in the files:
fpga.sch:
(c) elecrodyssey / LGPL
